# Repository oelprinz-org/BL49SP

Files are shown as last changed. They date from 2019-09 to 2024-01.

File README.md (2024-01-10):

# BL49SP  -  V0.0.3
Wideband Lambda Controller with Bosch CJ125 and LSU 4.9<br/>
Usable as a stand-alone controller or as a add-in for your own design. 2-layer pcb - single side soldered<br/>

20.04.2020 - Version 0.0.1: basic tests are done, seems to be in a working state<br/>

Version 0.0.1 - basic functions implemented: 0,5V - 4,5V equals AFR10-20<br/>

Version 0.0.2 - modifications for automated production process done - PCBs arrived - further tests needed<br/>

Version 0.0.2a - minor corrections on bottom silkscreen<br/>

Version 0.0.3 - minor corrections / pins added to connect OLED-Display<br/>

Update 04.09.2020 - Version 0.0.2: First tests have shown the finished lambda controller in an working state.<br/>
In idle mode Uout is 2,39V (Lambda 1,00).<br/>
In running mode we have a Uout of 4,56V at AFR20 and a Uout of 0,54V at AFR10.<br/>
All measurements have been done with a uncalibrated Multimeter and must be verified with a calibrated device.<br/>
Possibly there is some room for more finetuning or improvements, but until here all looks fine so far. <br/>
Current draw is only some milliAmps in idle mode, something around 1,7 A while heating and 0,7 A in running mode.<br/>

Update 17.09.2020 - Added some illustrations to the wiki how to connect the V0.0.2 board: https://github.com/oelprinz-org/BL49SP/wiki/Connecting-the-board-V0.0.2

V0.0.3 fabrication files for Jlcpcb: https://github.com/oelprinz-org/BL49SP/tree/master/fabrication/V0.0.3

not yet - Precompiled firmware files and fuse settings you can find at https://github.com/oelprinz-org/BL49SP/tree/master/software/V0.0.3/Arduino/BL49SP/Build<br/>

Interactive BOM for easier hand-soldering you can download from the github (BL49SP/hardware/V0.0.3/bom)
or access online here: http://oelprinz.org/products/BL49SP/hardware/V0.0.3/iBOM/ibom.html <br/>

Quick link to schematic: https://github.com/oelprinz-org/BL49SP/blob/master/hardware/V0.0.3/schematics.pdf <br/>

### Bosch CJ125 (LQFP32 package) part numbers

|Bosch part number|
|:----------------|
|30615|
|40103|
|30522|

### Suitable Bosch lambda probes

Basically, the Bosch probes whose numbers start with **0 258 017** will fit, also Bosch **0 281 004**.  
Bosch numbers beginning with **0 258 007** are *LSU 4.2* probes and will not fit.

|Bosch number  |Length overall|Comment|
|---|---|---|
|0 258 017 012 |1060mm||
|0 258 017 025 |1000mm|Bosch motorsport part|
|0 281 004 028 |540mm|common probe for diesel engines|
|0 258 017 029 |620mm|grey, used by BMW after 09/2006 (1178 7539124)|
|0 258 017 038 |340mm|grey, used by BMW (11787537984)|
|0 258 017 092 |950mm|black, used by BMW (1178 7540167)|
|0 258 017 126 |680mm|black, used by BMW after 09/2006 (1178 7561410)|
|0 281 004 150 |1215mm||
|0 281 004 184 |1000mm||
|...|||

### LSU4.9 probe pinout

|Pin#|Color|Description|Symbol|
|----|-----|---|---|
|1|red|Pump current APE|IP|
|2|yellow|Virtual ground IPN|VM|
|3|white|Heater voltage H-|Uh-|
|4|grey|Heater voltaget H+|Uh+|
|5|green|Trim Resistor RT|IA|
|6|black|Nernst voltage UN|RE| <br/>

<p align="center">
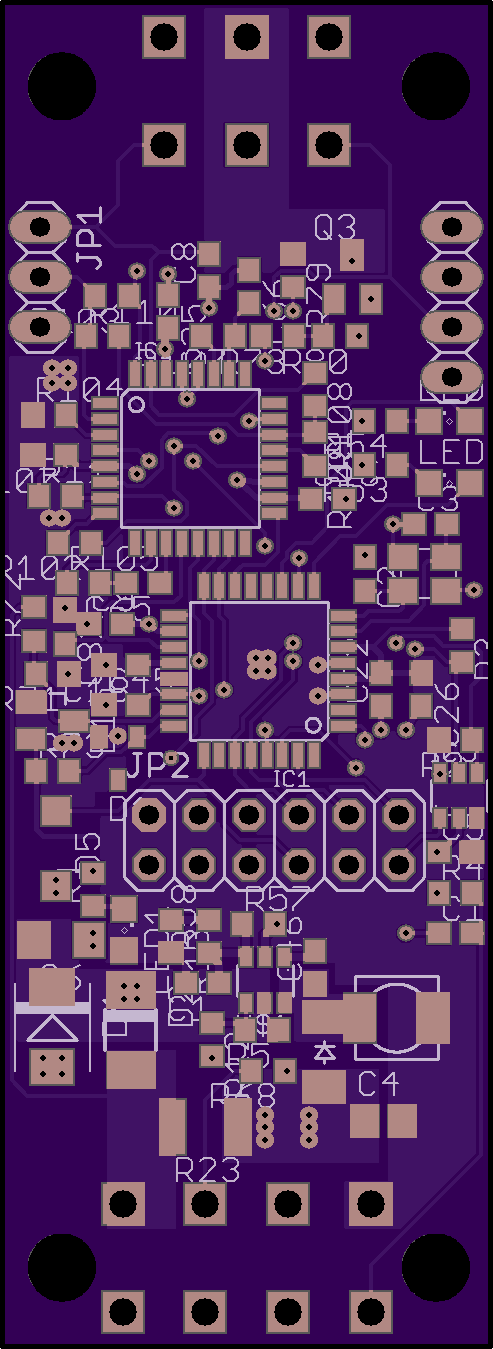
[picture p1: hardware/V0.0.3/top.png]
Top Side
  
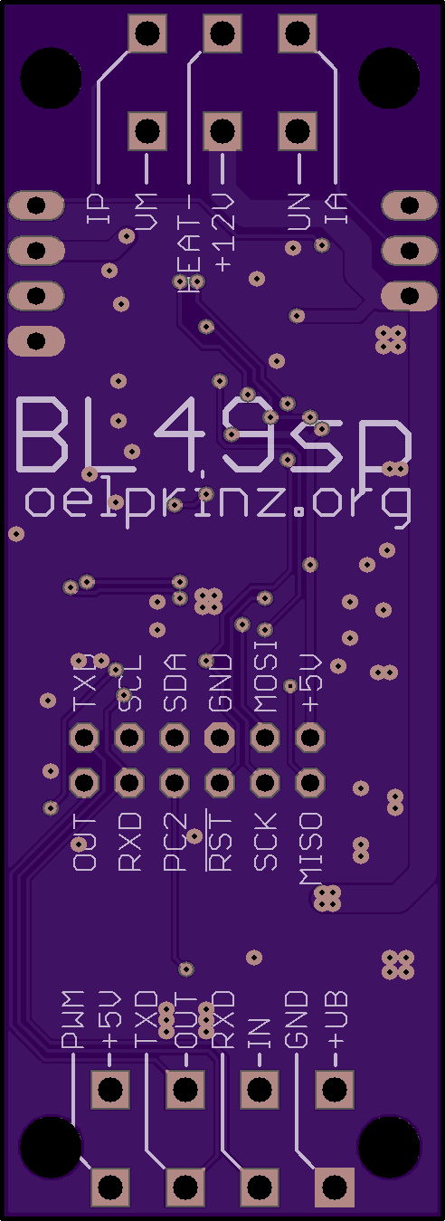
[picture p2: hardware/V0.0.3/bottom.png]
Bottom Side
  <br/>
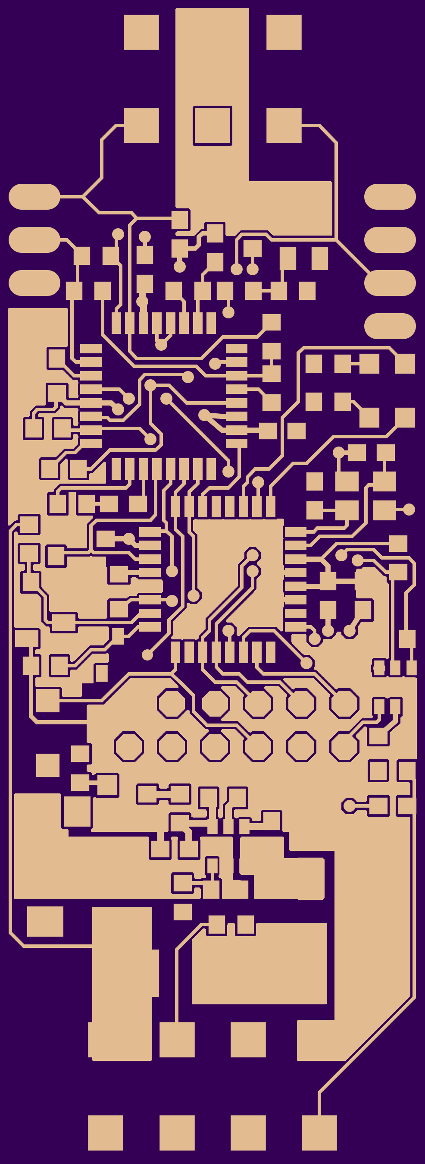
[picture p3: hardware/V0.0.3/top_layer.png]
Top Layer
  
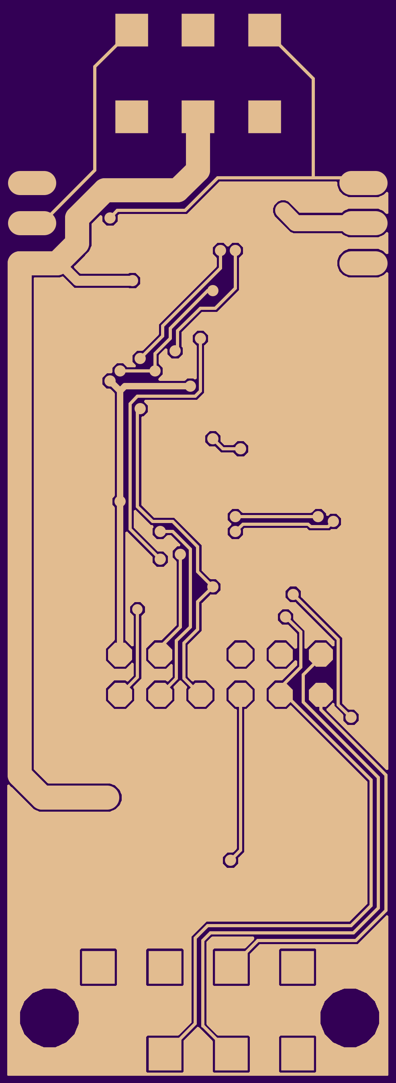
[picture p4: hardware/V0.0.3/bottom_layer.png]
Bottom Layer
  
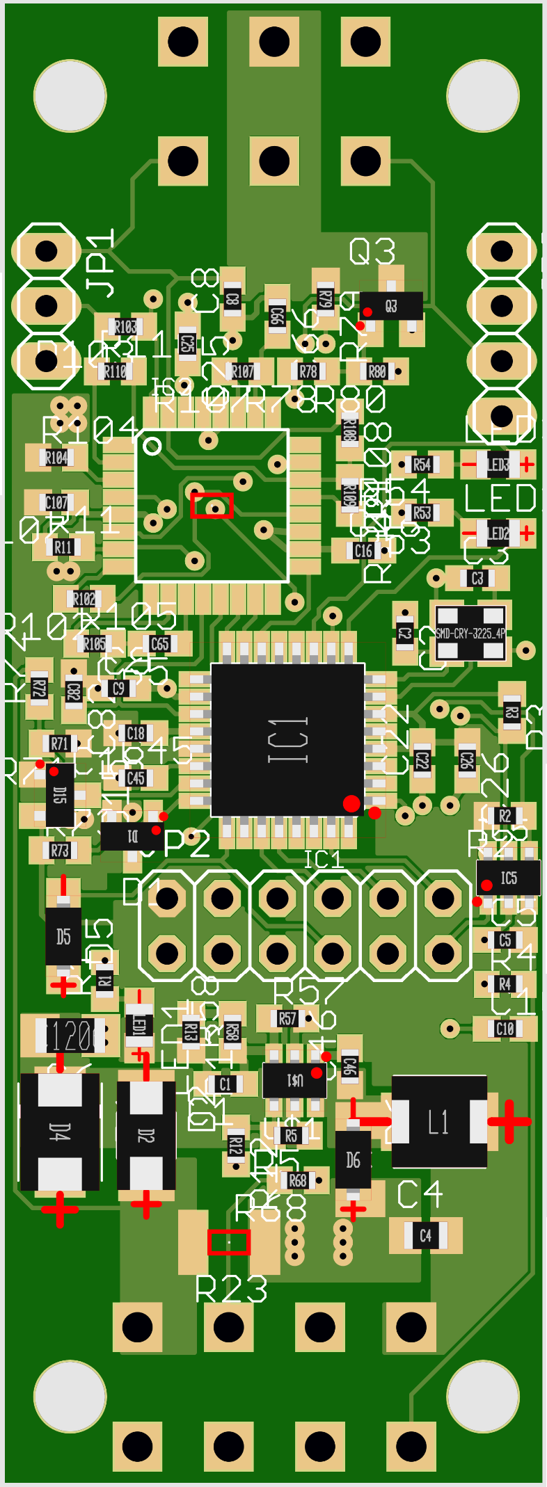
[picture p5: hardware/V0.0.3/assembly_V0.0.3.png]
Assembly
  
  
</p>

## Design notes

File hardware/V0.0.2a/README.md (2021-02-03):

# BL49SP - V0.0.2a

Version 0.0.1 - basic functions implemented: 0,5V - 4,5V equals AFR10-20<br/>

Version 0.0.2 - modifications for automated production process done - PCBs arrived - further tests needed<br/>

Version 0.0.2a - minor corrections on bottom silkscreen<br/>

Update 04.09.2020 - Version 0.0.2: First tests have shown the finished lambda controller in an working state.<br/>
In idle mode Uout is 2,39V (Lambda 1,00).<br/>
In running mode we have a Uout of 4,56V at AFR20 and a Uout of 0,54V at AFR10.<br/>
All measurements have been done with a uncalibrated Multimeter and must be verified with a calibrated device.<br/>
Possibly there is some room for more finetuning or improvements, but until here all looks fine so far. <br/>
Current draw is only some milliAmps in idle mode, something around 1,7 A while heating and 0,7 A in running mode.<br/>

Update 17.09.2020 - Added some illustrations to the wiki how to connect the board: https://github.com/oelprinz-org/BL49SP/wiki/Connecting-the-board-V0.0.2

Update 12.11.2020 - Added fabrication files for Jlcpcb: https://github.com/oelprinz-org/BL49SP/tree/master/fabrication/V0.0.2a

Precompiled firmware files and fuse settings you can find at https://github.com/oelprinz-org/BL49SP/tree/master/software/V0.0.2/Arduino/BL49SP/Build<br/>

Interactive BOM for easier hand-soldering you can download from the github (BL49SP/hardware/V0.0.2/bom)
or access online here: https://oelprinz.000webhostapp.com/BL49SP/V0.0.2/iBOM/ibom.html <br/>

Quick link to schematic: https://github.com/oelprinz-org/BL49SP/blob/master/hardware/V0.0.2/schematics.pdf <br/>

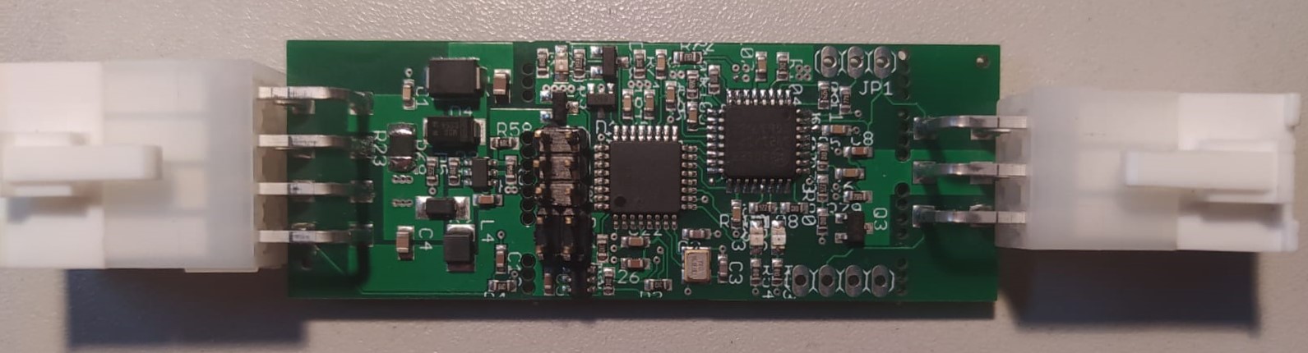
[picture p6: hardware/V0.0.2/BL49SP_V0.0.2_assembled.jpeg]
Assembled Prototype


<p align="center">
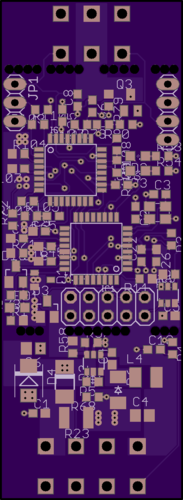
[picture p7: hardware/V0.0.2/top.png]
  
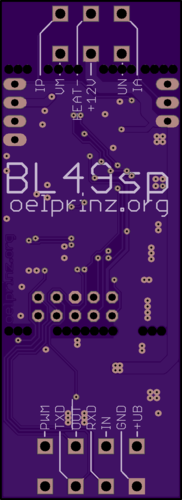
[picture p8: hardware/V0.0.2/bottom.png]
  <br/>
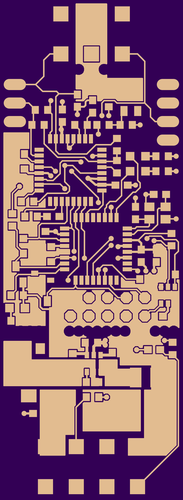
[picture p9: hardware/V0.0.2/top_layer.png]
  
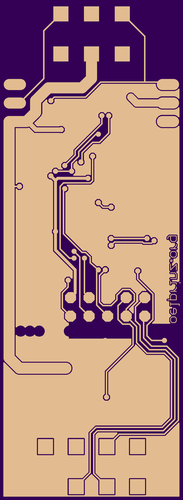
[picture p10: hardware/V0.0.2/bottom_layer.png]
  
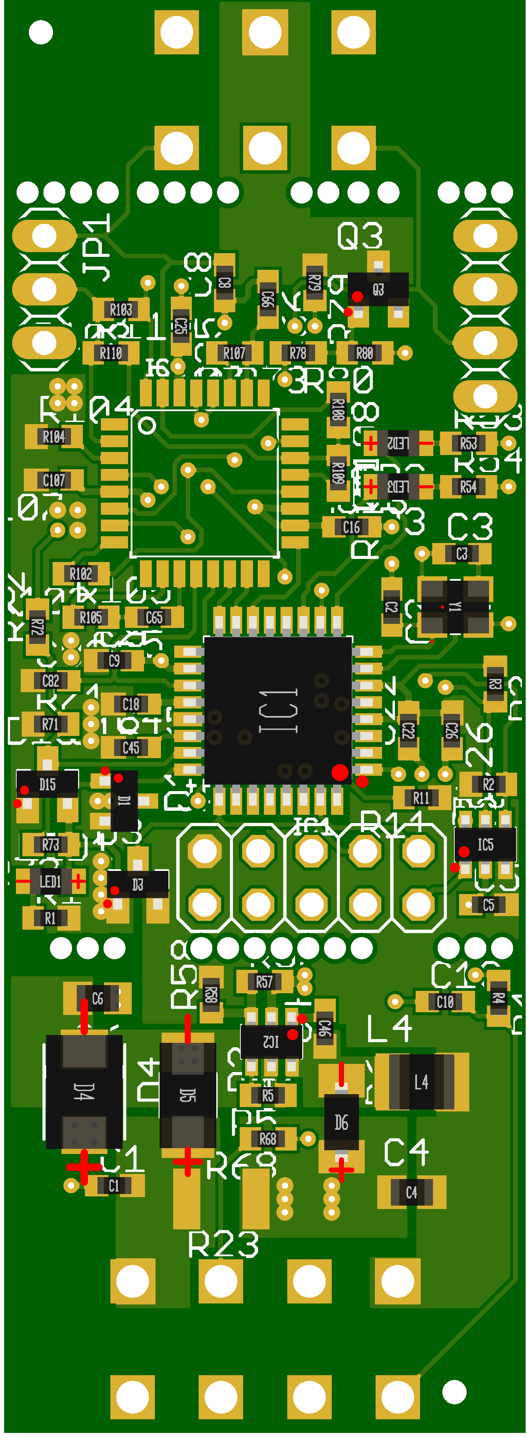
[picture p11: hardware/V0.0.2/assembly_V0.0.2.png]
assembly
  
  
</p>

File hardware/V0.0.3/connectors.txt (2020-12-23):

Needed Connectors and Pins are Molex Mini-Fit Jr 5569:

1x Pin Header 2x4P: 3930-1080
1x Pin Header 2x3P: 3930-1060
1x Contact housing female 2x4P: 3901-2085
1x Contact housing female 2x3P: 3901-2065
14x Crimp socket Female: 3900-0039

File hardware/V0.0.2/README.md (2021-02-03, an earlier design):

# BL49SP - V0.0.2

Version 0.0.1 - basic functions implemented: 0,5V - 4,5V equals AFR10-20<br/>

Version 0.0.2 - modifications for automated production process done - PCBs arrived - further tests needed<br/>

Version 0.0.2a - minor corrections on bottom silkscreen<br/>

Update 04.09.2020 - Version 0.0.2: First tests have shown the finished lambda controller in an working state.<br/>
In idle mode Uout is 2,39V (Lambda 1,00).<br/>
In running mode we have a Uout of 4,56V at AFR20 and a Uout of 0,54V at AFR10.<br/>
All measurements have been done with a uncalibrated Multimeter and must be verified with a calibrated device.<br/>
Possibly there is some room for more finetuning or improvements, but until here all looks fine so far. <br/>
Current draw is only some milliAmps in idle mode, something around 1,7 A while heating and 0,7 A in running mode.<br/>

Update 17.09.2020 - Added some illustrations to the wiki how to connect the board: https://github.com/oelprinz-org/BL49SP/wiki/Connecting-the-board-V0.0.2

Update 12.11.2020 - Added fabrication files for Jlcpcb: https://github.com/oelprinz-org/BL49SP/tree/master/fabrication/V0.0.2a

Precompiled firmware files and fuse settings you can find at https://github.com/oelprinz-org/BL49SP/tree/master/software/V0.0.2/Arduino/BL49SP/Build<br/>

Interactive BOM for easier hand-soldering you can download from the github (BL49SP/hardware/V0.0.2/bom)
or access online here: https://oelprinz.000webhostapp.com/BL49SP/V0.0.2/iBOM/ibom.html <br/>

Quick link to schematic: https://github.com/oelprinz-org/BL49SP/blob/master/hardware/V0.0.2/schematics.pdf <br/>

Assembled Prototype

<p align="center">
  Top Side
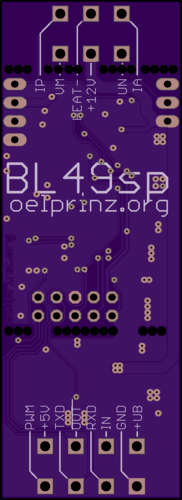
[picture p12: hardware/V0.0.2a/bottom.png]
  <br/>
  Top Side
  accessibility text
  assembly
  
</p>

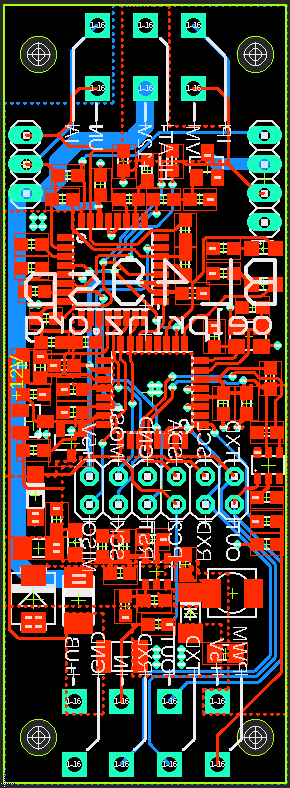
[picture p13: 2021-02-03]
hardware/V0.0.3/BL49SP_Board_V0.0.3.png

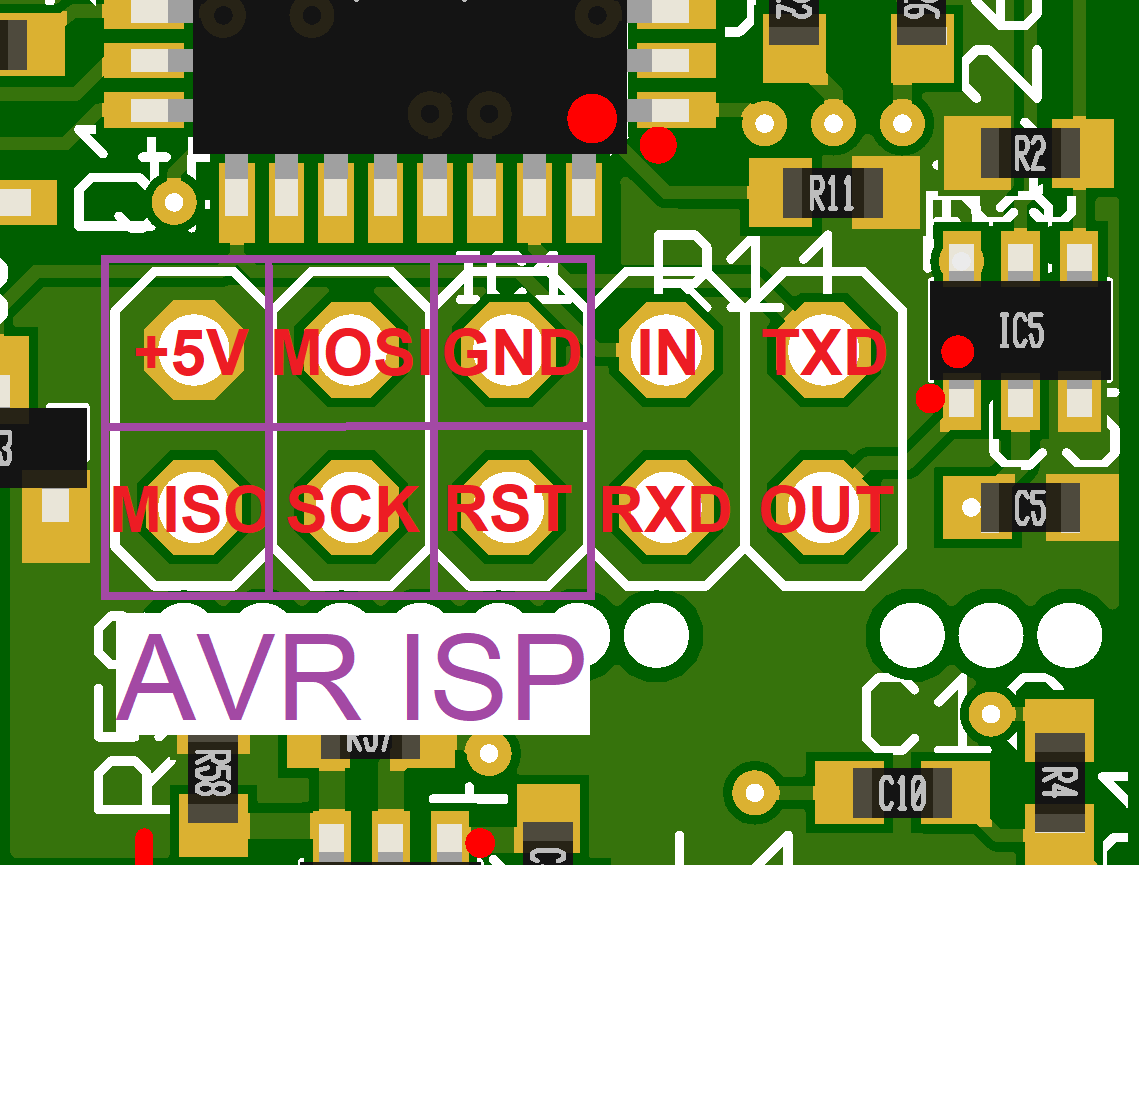
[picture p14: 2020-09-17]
wiki/images/PinHeader.png

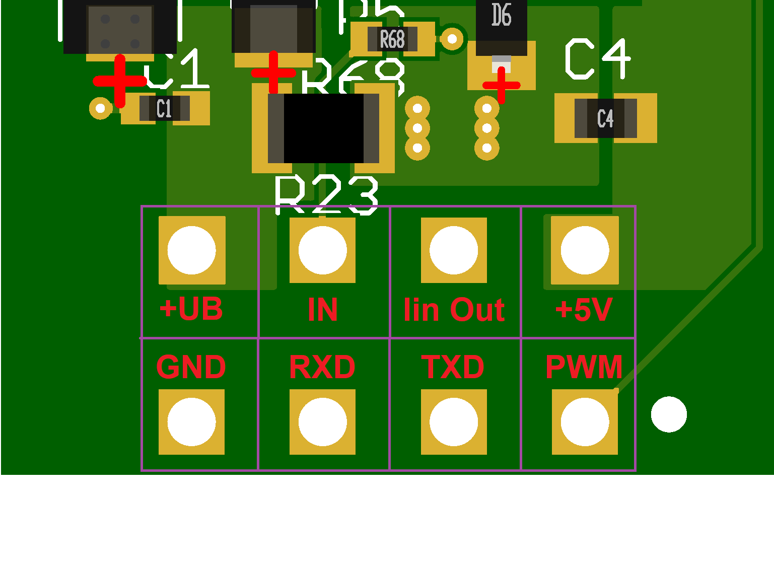
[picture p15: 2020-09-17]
wiki/images/PowerSupply_IOs.png

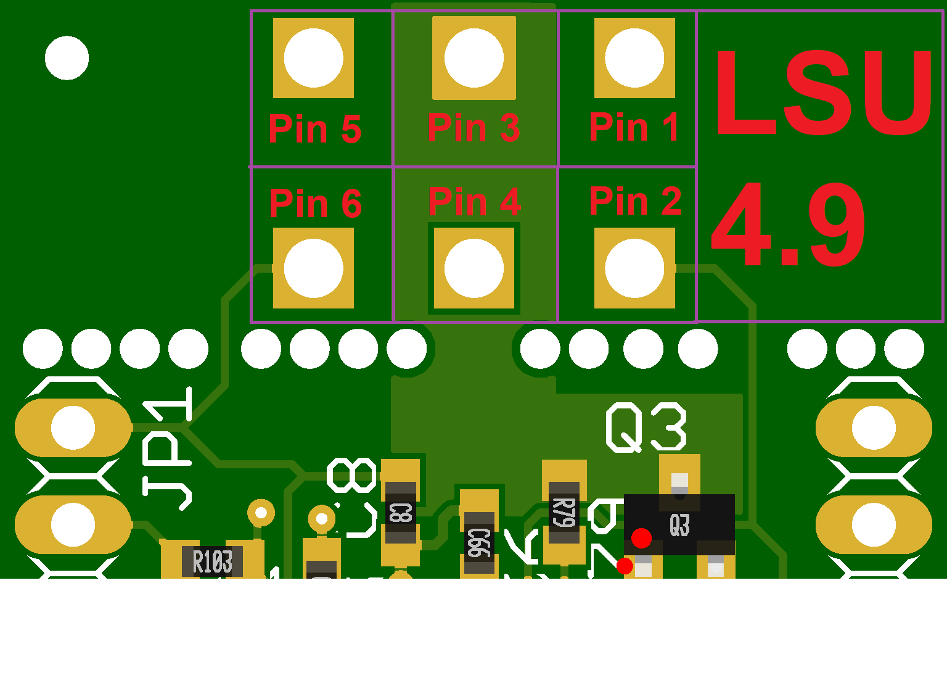
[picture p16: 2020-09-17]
wiki/images/LambdaConnector.png

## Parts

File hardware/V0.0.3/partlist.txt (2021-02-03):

Part     Value           Device          Package          Library                 Sheet

C1       33p             C-EUC0603       C0603            rcl                     1
C2       18p             C-EUC0603       C0603            rcl                     1
C3       18p             C-EUC0603       C0603            rcl                     1
C4       10u             C-EUC0805       C0805            rcl                     1
C5       1u              C-EUC0603       C0603            rcl                     1
C6       22u             C-EUC1206       C1206            rcl                     1
C8       2n2             C-EUC0603       C0603            rcl                     1
C9       100n            C-EUC0603       C0603            rcl                     1
C10      1u              C-EUC0603       C0603            rcl                     1
C16      100n            C-EUC0603       C0603            rcl                     1
C18      100n            C-EUC0603       C0603            rcl                     1
C22      100n            C-EUC0603       C0603            rcl                     1
C25      100n            C-EUC0603       C0603            rcl                     1
C26      1u              C-EUC0603       C0603            rcl                     1
C45      33n             C-EUC0603       C0603            rcl                     1
C46      100n            C-EUC0603       C0603            rcl                     1
C65      100n            C-EUC0603       C0603            rcl                     1
C66      100n            C-EUC0603       C0603            rcl                     1
C82      33n             C-EUC0603       C0603            rcl                     1
C107     100n            C-EUC0603       C0603            rcl                     1
D1       LM4041DIM3-1.2  LM4041A12DBZ    DBZ_R-PDSO-G3    texas                   1
D2       SS54            DIODE-DO-214AC  DO-214AC         diode                   1
D4       SMBJ18A         SUPPRESSOR-SMBJ SMBJ             diode                   1
D5                       DIODE-SOD123    SOD123           diode                   1
D6       B5819W          CGRM4001-G      SOD-123_MINI-SMA diode                   1
D15      BAT54S          BAT54S          SOT23            diode                   1
IC1      MEGA328         MEGA8-AI        TQFP32-08        atmel                   1
IC3      CJ125_32        CJ125_32        TQFP32-08        cj125                   1
IC5      MCP4725         MCP4725         SOT23-6          mcp4725                 1
JP1                      PINHD-1X3       1X03             pinhead                 1
JP2                      PINHD-2X6       2X06             pinhead                 1
JP3                      PINHD-1X4       1X04             pinhead                 1
L1       MWSA0402S-3R3MT MWSA0402S-3R3MT MWSA0402S-3R3MT  MWSA0402S-3R3MT         1
LED1     blau            LEDSML0805      SML0805          led                     1
LED2     blau            LEDSML0805      SML0805          led                     1
LED3     blau            LEDSML0805      SML0805          led                     1
Q3       AO3400A         BSS123          SOT23            transistor-small-signal 1
R1       820R            R-EU_R0603      R0603            rcl                     1
R2       10k             R-EU_R0603      R0603            rcl                     1
R3       10k             R-EU_R0603      R0603            rcl                     1
R4       1k              R-EU_R0603      R0603            rcl                     1
R5       100k            R-EU_R0603      R0603            rcl                     1
R11      10k             R-EU_R0603      R0603            rcl                     1
R12      22k             R-EU_R0603      R0603            rcl                     1
R13      100k            R-EU_R0603      R0603            rcl                     1
R23      B72530V1140S262 VARISTORCN1210  CT/CN1210        varistor                1
R53      1k              R-EU_R0603      R0603            rcl                     1
R54      1k              R-EU_R0603      R0603            rcl                     1
R57      24k             R-EU_R0603      R0603            rcl                     1
R58      24k             R-EU_R0603      R0603            rcl                     1
R68      470R            R-EU_R0603      R0603            rcl                     1
R71      10k             R-EU_R0603      R0603            rcl                     1
R72      39k             R-EU_R0603      R0603            rcl                     1
R73      39k             R-EU_R0603      R0603            rcl                     1
R78      4k7             R-EU_R0603      R0603            rcl                     1
R79      6k8             R-EU_R0603      R0603            rcl                     1
R80      100k            R-EU_R0603      R0603            rcl                     1
R102     300/1%          R-EU_R0603      R0603            rcl                     1
R103     61R9            R-EU_R0603      R0603            rcl                     1
R104     10k             R-EU_R0603      R0603            rcl                     1
R105     31k6/1%         R-EU_R0603      R0603            rcl                     1
R107     100k            R-EU_R0603      R0603            rcl                     1
R108     100k            R-EU_R0603      R0603            rcl                     1
R109     4k7             R-EU_R0603      R0603            rcl                     1
R110     470k            R-EU_R0603      R0603            rcl                     1
U$1      MP2451          MP2359          SOT23-6          MP2359                  1
U$4      X322516MLB4SI   X322516MLB4SI   X322516MLB4SI    X322516MLB4SI           1

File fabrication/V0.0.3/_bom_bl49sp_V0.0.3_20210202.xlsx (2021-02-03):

Comment | Value | Designator | Footprint | LCSC Part #
0603WAF1003T5E | 100kΩ ±1% 0.1W ±100ppm/℃ 0603 Chip Resistor - Surface Mount | R5,R13,R80,R107,R108 | 0603_R | C25803 (https://lcsc.com/product-detail/Chip-Resistor-Surface-Mount_Uniroyal-Elec-0603WAF1003T5E_C25803.html/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)
CC0603KRX7R9BB104 | 100nF ±10% 50V X7R 0603 Multilayer Ceramic Capacitors MLCC – SMD/SMT | C9,C16,C18,C22,C25,C46,C65,C66,C107 | 0603_C | C14663 (https://lcsc.com/product-detail/Multilayer-Ceramic-Capacitors-MLCC-SMD-SMT_100nF-104-10-50V_C14663.html/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)
0603WAF1002T5E | 10kΩ ±1% 0.1W ±100ppm/℃ 0603 Chip Resistor - Surface Mount | R2,R3,R11,R71,R104 | 0603_R | C25804 (https://lcsc.com/product-detail/Chip-Resistor-Surface-Mount_Uniroyal-Elec-0603WAF1002T5E_C25804.html/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)
MM1Z5V1 | ZENER DIODE 5,1V | D5 | SOD-123 | C81601 (https://lcsc.com/product-detail/Zener-Diodes_MM1Z5V1_C81601.html/?href=jlc-SMT)
CL10C180JB8NNNC | 18pF ±5% 50V C0G 0603 Multilayer Ceramic Capacitors MLCC – SMD/SMT | C2,C3 | 0603_C | C1647 (https://lcsc.com/product-detail/Multilayer-Ceramic-Capacitors-MLCC-SMD-SMT_SAMSUNG_CL10C180JB8NNNC_18pF-180-5-50V_C1647.html/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)
0603WAF8200T5E | 820Ω ±1% 0.1W ±100ppm/℃ 0603 Chip Resistor - Surface Mount | R1 | 0603_R | C23253 (https://lcsc.com/product-detail/Chip-Resistor-Surface-Mount_Uniroyal-Elec-0603WAF8200T5E_C23253.html/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)
0603WAF1001T5E | 1kΩ ±1% 0.1W ±100ppm/℃ 0603 Chip Resistor - Surface Mount | R4,R53,R54 | 0603_R | C21190 (https://lcsc.com/product-detail/Chip-Resistor-Surface-Mount_Uniroyal-Elec-0603WAF1001T5E_C21190.html/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)
CL10C330JB8NNNC | 33pF ±10% 50V X7R 0603 Multilayer Ceramic Capacitors MLCC – SMD/SMT | C1 | 0603_C | C1663 (https://lcsc.com/product-detail/Multilayer-Ceramic-Capacitors-MLCC-SMD-SMT_SAMSUNG_CL10C330JB8NNNC_33pF-330-5-50V_C1663.html/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)
CL10A105KB8NNNC | 1uF ±10% 50V X5R 0603 Multilayer Ceramic Capacitors MLCC – SMD/SMT | C5,C10,C26 | 0603_C | C15849 (https://lcsc.com/product-detail/Multilayer-Ceramic-Capacitors-MLCC-SMD-SMT_SAMSUNG_CL10A105KB8NNNC_1uF-105-10-50V_C15849.html/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)
CL21A106KAYNNNE | 10uF ±20% 25V X5R 0805 Multilayer Ceramic Capacitors MLCC – SMD/SMT | C4 | 0805_C | C15850 (https://lcsc.com/product-detail/Multilayer-Ceramic-Capacitors-MLCC-SMD-SMT_SAMSUNG_CL21A106KAYNNNE_10uF-106-10-25V_C15850.html/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)
C3216X5R1V226MTJ00E | 22UF ±20% 35V X5R 1206 MULTILAYER CERAMIC CAPACITORS MLCC | C6 | 1206_C | C342620 (https://lcsc.com/product-detail/Multilayer-Ceramic-Capacitors-MLCC-SMD-SMT_TDK-C3216X5R1V226MTJ00E_C342620.html/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)
0603B222K500NT | 2.2nF ±10% 50V X7R 0603 Multilayer Ceramic Capacitors MLCC - SMD/SMT | C8 | 0603_C | C1604 (https://lcsc.com/product-detail/Multilayer-Ceramic-Capacitors-MLCC-SMD-SMT_2-2nF-222-10-50V_C1604.html/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)
0603WAF3000T5E | 300Ω ±1% 0.1W ±100ppm/℃ 0603 Chip Resistor - Surface Mount | R102 | 0603_R | C23025
0603WAF3162T5E | 31.6kΩ ±1% ±1% 0.1W ±100ppm/℃ 0603 Chip Resistor - Surface Mount | R105 | 0603_R | C25967 (https://lcsc.com/product-detail/Chip-Resistor-Surface-Mount_Uniroyal-Elec-0603WAF3162T5E_C25967.html/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)
CL10B333KB8NNNC | 33nF ±10% 50V X7R 0603 Multilayer Ceramic Capacitors MLCC – SMD/SMT | C45,C82 | 0603_C | C21117 (https://lcsc.com/product-detail/Multilayer-Ceramic-Capacitors-MLCC-SMD-SMT_SAMSUNG_CL10B333KB8NNNC_33nF-333-10-50V_C21117.html/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)
0603WAF3902T5E | 39kΩ ±1% 0.1W ±100ppm/℃ 0603 Chip Resistor - Surface Mount | R72,R73 | 0603_R | C23153 (https://lcsc.com/product-detail/Chip-Resistor-Surface-Mount_Uniroyal-Elec-0603WAF3902T5E_C23153.html/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)
0603WAF2402T5E | 24kΩ ±1% 0.1W ±100ppm/℃ 0603 Chip Resistor - Surface Mount | R57,R58 | 0603_R | C23352 (https://lcsc.com/product-detail/Chip-Resistor-Surface-Mount_Uniroyal-Elec-0603WAF2402T5E_C23352.html/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)
0603WAF4703T5E | 470kΩ ±1% 0.1W ±100ppm/℃ 0603 Chip Resistor - Surface Mount | R110 | 0603_R | C23178 (https://lcsc.com/product-detail/Chip-Resistor-Surface-Mount_Uniroyal-Elec-0603WAF4703T5E_C23178.html/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)
0603WAF4700T5E | 470Ω ±1% 0.1W ±100ppm/℃ 0603 Chip Resistor - Surface Mount | R68 | 0603_R | C23179 (https://lcsc.com/product-detail/Chip-Resistor-Surface-Mount_Uniroyal-Elec-0603WAF4700T5E_C23179.html/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)
0603WAF4701T5E | 4.7kΩ ±1% 0.1W ±100ppm/℃ 0603 Chip Resistor - Surface Mount | R78,R109 | 0603_R | C23162 (https://lcsc.com/product-detail/Chip-Resistor-Surface-Mount_Uniroyal-Elec-0603WAF4701T5E_C23162.html/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)
0603WAF619JT5E | 61.9Ω ±1% 0.1W ±200ppm/℃ 0603 Chip Resistor - Surface Mount | R103 | 0603_R | C23092 (https://lcsc.com/product-detail/Chip-Resistor-Surface-Mount_Uniroyal-Elec-0603WAF619JT5E_C23092.html/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)
0603WAF2202T5E | 22kΩ ±1% 0.1W ±100ppm/℃ 0603 Chip Resistor - Surface Mount | R12 | 0603_R | C31850 (https://lcsc.com/product-detail/Chip-Resistor-Surface-Mount_Uniroyal-Elec-0603WAF2202T5E_C31850.html/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)
0603WAF6801T5E | 6.8kΩ ±1% 0.1W ±100ppm/℃ 0603 Chip Resistor - Surface Mount | R79 | 0603_R | C23212 (https://lcsc.com/product-detail/Chip-Resistor-Surface-Mount_Uniroyal-Elec-0603WAF6801T5E_C23212.html/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)
B5819W | 40V 1A 600mV @ 1A SOD-123 Schottky Barrier Diodes (SBD) | D6 | SOD-123 | C8598
B72530V1140S262 | 22V 400A Varistor Circuit Surface Mount, MLCV 1210 (3225 Metric) | R23 | CT/CN1210 | n/a
BAT54S | 30V 200mA 800mV @ 100mA SOT-23(SOT-23-3) Schottky Barrier Diodes (SBD) | D15 | SOT23 | C181201 (https://lcsc.com/product-detail/Schottky-Barrier-Diodes-SBD_BAT54S_C181201.html/?href=jlc-SMT)
CJ125_32 | Bosch CJ125 (30522) | IC3 | TQFP32-08 | n/a
AO3400A | N Channel 30V 5.7A 1.5V @ 250uA 26.5mΩ @ 5.7A,10V 1.4W SOT-23-3L MOSFET | Q3 | SOT-23-3L | C347475
LM4041C12IDBZR | Voltage References 1.225V ±0.5% 100ppm/°C SOT-23 | D1 | SOT-23-3 | C189195
MWSA0402S-3R3MT | 3.3UH ±20% 3.3A 87MΩ SMD,4.2X4.4X2.0MM POWER INDUCTORS | L1 | SMD-4.2x4.4x2.0 | C408336 (https://lcsc.com/product-detail/Power-Inductors_Sunlord-MWSA0402S-3R3MT_C408336.html/?href=jlc-SMT)
MCP4725A0T-E/CH | Voltage-Buffered I2C SOT-23-6 Digital To Analog Converters (DACs) | IC5 | SOT23-6 | C144198 (https://lcsc.com/product-detail/Digital-To-Analog-Converters-DACs_MICROCHIP_MCP4725A0T-E-CH_MCP4725A0T-E-CH_C144198.html/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)
ATMEGA328P-AU | 8-Bit FLASH AVR 20MHz 1.8V ~ 5.5V TQFP-32_7x7x08P ATMEL & AVR | IC1 | TQFP32-08 | C14877 (https://lcsc.com/product-detail/ATMEL-AVR_ATMEL_ATMEGA328P-AU_ATMEGA328P-AU_C14877.html/?href=jlc-SMT)
MP2451DT-LF-Z | TSOT-23-6 DC-DC Converters | U$1 | TSOT-23-6 | C14123 (https://lcsc.com/product-detail/DC-DC-Converters_MPS_MP2451DT-LF-Z_MP2451DT-LF-Z_C14123.html/?href=jlc-SMT)
SMBJ18A | TVS SMB(DO-214AA) ROHS | D4 | DO-214AA | C78412
SS54 | 40V 5A 550mV @ 5A SMA(DO-214AC) Schottky Barrier Diodes (SBD) | D2 | DO-214AA | C22452 (https://lcsc.com/product-detail/Schottky-Barrier-Diodes-SBD_MDD-Microdiode-Electronics-SS54_C22452.html/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)
LEDBLUE0805 | 0805 Light Emitting Diodes (LED) blue | LED1 | SML0805 | C2293 (https://lcsc.com/product-detail/Light-Emitting-Diodes-LED_Hubei-KENTO-Elec-Blue-light_C2293.html/?href=jlc-SMT)
FC-2012HRK-620D | 0805 Light Emitting Diodes (LED) red | LED2 | SML0805 | C84256 (https://lcsc.com/product-detail/Light-Emitting-Diodes-LED_Red-LED-SMDLED-80-180mcd_C84256.html/?href=jlc-SMT)
LEDGREEN0805 | 0805 Light Emitting Diodes (LED) green | LED3 | SML0805 | C2297 (https://lcsc.com/product-detail/Light-Emitting-Diodes-LED_Green-0805-Iv-207-249-mcd-atIF-20mA_C2297.html/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)
X322516MLB4SI | SMD CRYSTAL RESONATORS 16MHZ ±10PPM SMD-3225_4P | U$4 | SMD-3225 | C13738 (https://lcsc.com/product-detail/SMD-Crystal-Resonators_Yangxing-Tech-X322516MLB4SI_C13738.html/?href=jlc-SMT)
 | D5

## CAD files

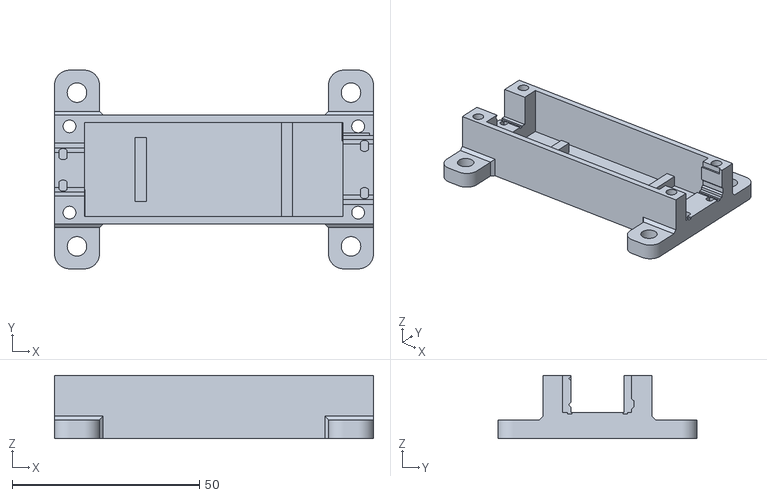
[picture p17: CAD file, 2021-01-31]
hardware/case/Case_V0.0.2a.stl
85.1 x 53.0 x 16.9

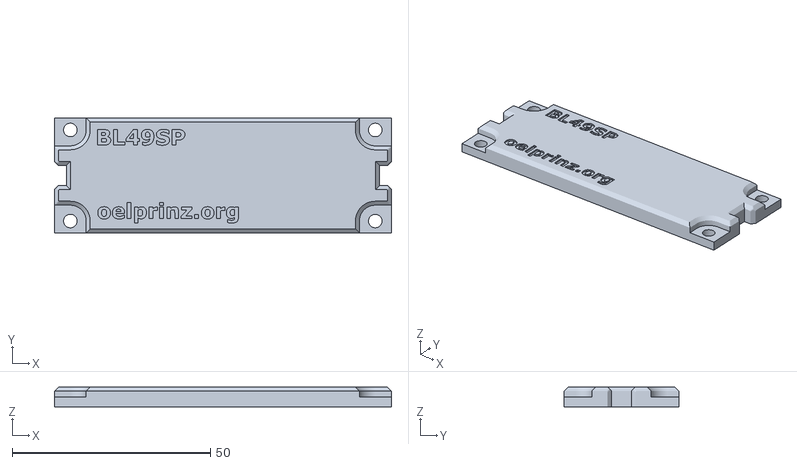
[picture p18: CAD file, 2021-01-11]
hardware/case/Cover_V0.0.2a.stl
85.1 x 29.0 x 5.00

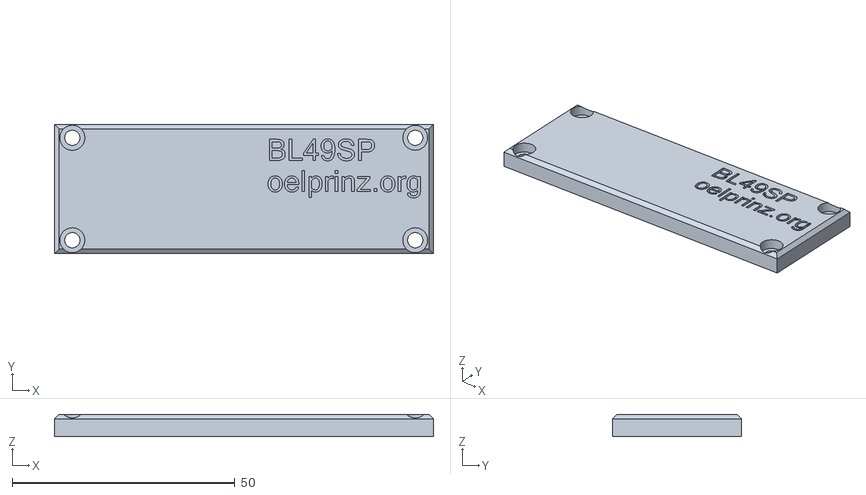
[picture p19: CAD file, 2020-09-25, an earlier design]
hardware/case/archive/Cover_V0.0.2.stl
85.1 x 29.0 x 5.00

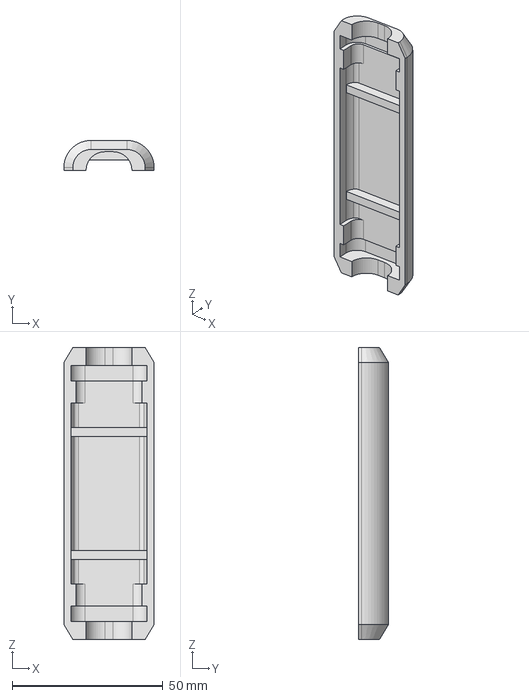
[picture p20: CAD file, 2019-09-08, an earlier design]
hardware/case/archive/case_bl49sp.stp
30.0 x 10.0 x 97.0 mm

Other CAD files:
hardware/case/Cover_V0.0.2a_2LED.stl
hardware/case/Cover_V0.0.2a_1LED.stl
hardware/case/archive/case_bl49sp.stl

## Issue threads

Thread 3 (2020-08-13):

Is there a BOM to enable parts ordering?

84ace, 2020-08-13:
Hi,

I noticed that the BOM and parts list can't really be used to identify the parts needed to assemble the board. Is there a parts reference somewhere so that I can order the parts needed.

Also, is there a KiCad .pro somewhere so that changes can be made?

Cheers,
Acea

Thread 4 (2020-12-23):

Connector types

h2oo2h, 2020-12-23:
What type of connectors do you use for sensor and supply?

chaoschris, 2020-12-23:
Hello,
needed Connectors and Pins are Molex Mini-Fit Jr 5569 :
1x Pin Header 2x4P: 3930-1080
1x Pin Header 2x3P: 3930-1060
1x Contact housing female 2x4P: 3901-2085
1x Contact housing female 2x3P: 3901-2065
14x Crimp socket Female: 3900-0039

Best regards,
Chris

Zitat von h2oo2h <notifications@github.com>:

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

chaoschris, 2020-12-23:
added the information now:
https://github.com/oelprinz-org/BL49SP/blob/master/hardware/V0.0.2/connectors.txt

Closed 2020-12-23.

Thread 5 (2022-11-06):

Stuck on preheat

dener4321, 2022-11-06:
```
	/* one step every second */
	if ((Abl.Tick - Abl.LastHeatTick) >= PROBE_PREHEAT_PERIOD)
	{
		/* Toggle heater LED */
		Out.Led2 ^= 1;
		/* Check if we have reached end phase */
		if ((Out.Heater >= end) || (In.UR < Abl.UROpt))
		{
			Abl.Mode = RUNNING;
		}
		else
		{
			Out.Heater += step;
			/* Limit heater voltage to end pulse width */
			if (Out.Heater > end) Out.Heater = end;
		}
		/* Save tick count */
		Abl.LastHeatTick = Abl.Tick
```

I seem to have encountered a problem in this code.
Out.heater += step
For example if you add 252 + 7 it won't give 259 it will give 3 because the variable is of type uint8 it goes up to 255 only. Then it will restart the heating process.

chaoschris, 2022-11-18:
Have you tested the corrected version of the software?

dener4321, 2023-01-20:
> Have you tested the corrected version of the software?

yes it is working

Closed 2023-01-20.

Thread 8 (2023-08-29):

Can't get it to burn bootloader.

GarrdenDog, 2023-08-29:
Hey, I've tried everything to upload sketch or burn bootloader(uspasp, ttl, arduino as isp) always throws error (not detecting, difrent signature or smth else)
avrdude: Yikes!  Invalid device signature.
         Double check connections and try again, or use -F to override
         this check.
or
stk500_recv()
The atmega was ordered from jlcpcb and soldered by them.
I ve tried uploading on not asembled board and fully aseambled board.

GarrdenDog, 2023-08-29:
avrdude: Version 6.3-20190619
         Copyright (c) 2000-2005 Brian Dean, http://www.bdmicro.com/
         Copyright (c) 2007-2014 Joerg Wunsch

         System wide configuration file is "C:\Users\mmuch\AppData\Local\Arduino15\packages\arduino\tools\avrdude\6.3.0-arduino17/etc/avrdude.conf"

         Using Port                    : COM6
         Using Programmer              : arduino
         Overriding Baud Rate          : 19200
         AVR Part                      : ATmega328P
         Chip Erase delay              : 9000 us
         PAGEL                         : PD7
         BS2                           : PC2
         RESET disposition             : dedicated
         RETRY pulse                   : SCK
         serial program mode           : yes
         parallel program mode         : yes
         Timeout                       : 200
         StabDelay                     : 100
         CmdexeDelay                   : 25
         SyncLoops                     : 32
         ByteDelay                     : 0
         PollIndex                     : 3
         PollValue                     : 0x53
         Memory Detail                 :

                                  Block Poll               Page                       Polled
           Memory Type Mode Delay Size  Indx Paged  Size   Size #Pages MinW  MaxW   ReadBack
           ----------- ---- ----- ----- ---- ------ ------ ---- ------ ----- ----- ---------
           eeprom        65    20     4    0 no       1024    4      0  3600  3600 0xff 0xff
           flash         65     6   128    0 yes     32768  128    256  4500  4500 0xff 0xff
           lfuse          0     0     0    0 no          1    0      0  4500  4500 0x00 0x00
           hfuse          0     0     0    0 no          1    0      0  4500  4500 0x00 0x00
           efuse          0     0     0    0 no          1    0      0  4500  4500 0x00 0x00
           lock           0     0     0    0 no          1    0      0  4500  4500 0x00 0x00
           calibration    0     0     0    0 no          1    0      0     0     0 0x00 0x00
           signature      0     0     0    0 no          3    0      0     0     0 0x00 0x00

         Programmer Type : Arduino
         Description     : Arduino
         Hardware Version: 2
         Firmware Version: 1.18
         Topcard         : Unknown
         Vtarget         : 0.0 V
         Varef           : 0.0 V
         Oscillator      : Off
         SCK period      : 0.1 us

avrdude: AVR device initialized and ready to accept instructions

Błąd przy wgrywaniu bootloadera.
Reading | ################################################## | 100% 0.00s

avrdude: Device signature = 0x535353
avrdude: Expected signature for ATmega328P is 1E 95 0F
         Double check chip, or use -F to override this check.

avrdude done.  Thank you.

chaoschris, 2023-08-31:
have you tested all connections between your programmer and the pins on the Atmega? One-by-one?

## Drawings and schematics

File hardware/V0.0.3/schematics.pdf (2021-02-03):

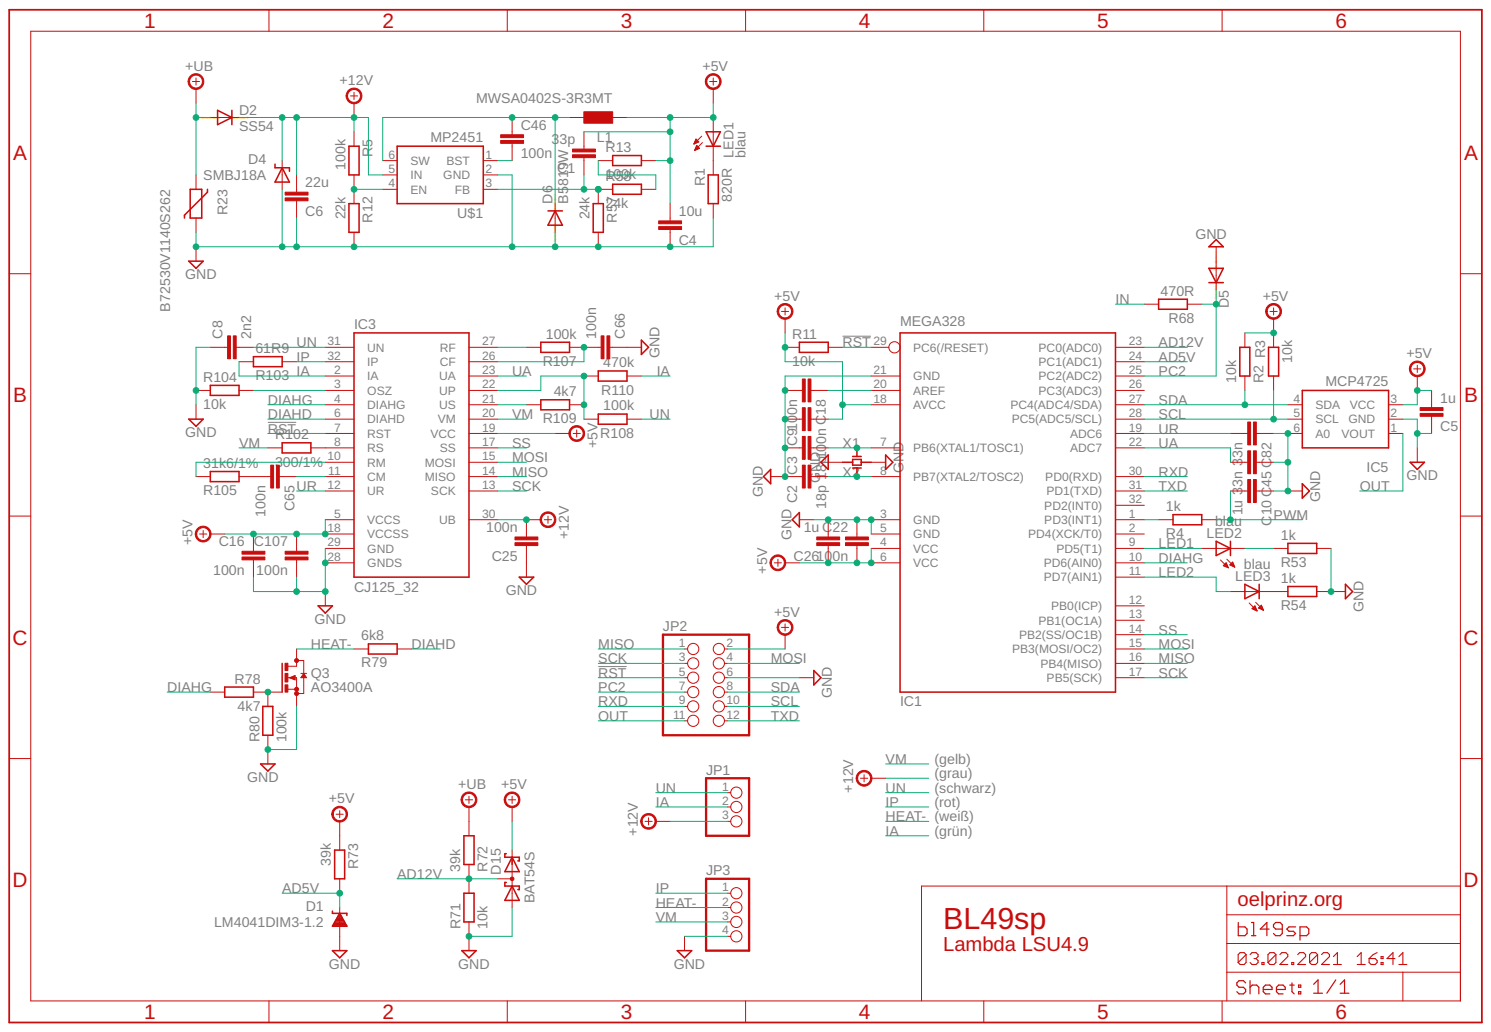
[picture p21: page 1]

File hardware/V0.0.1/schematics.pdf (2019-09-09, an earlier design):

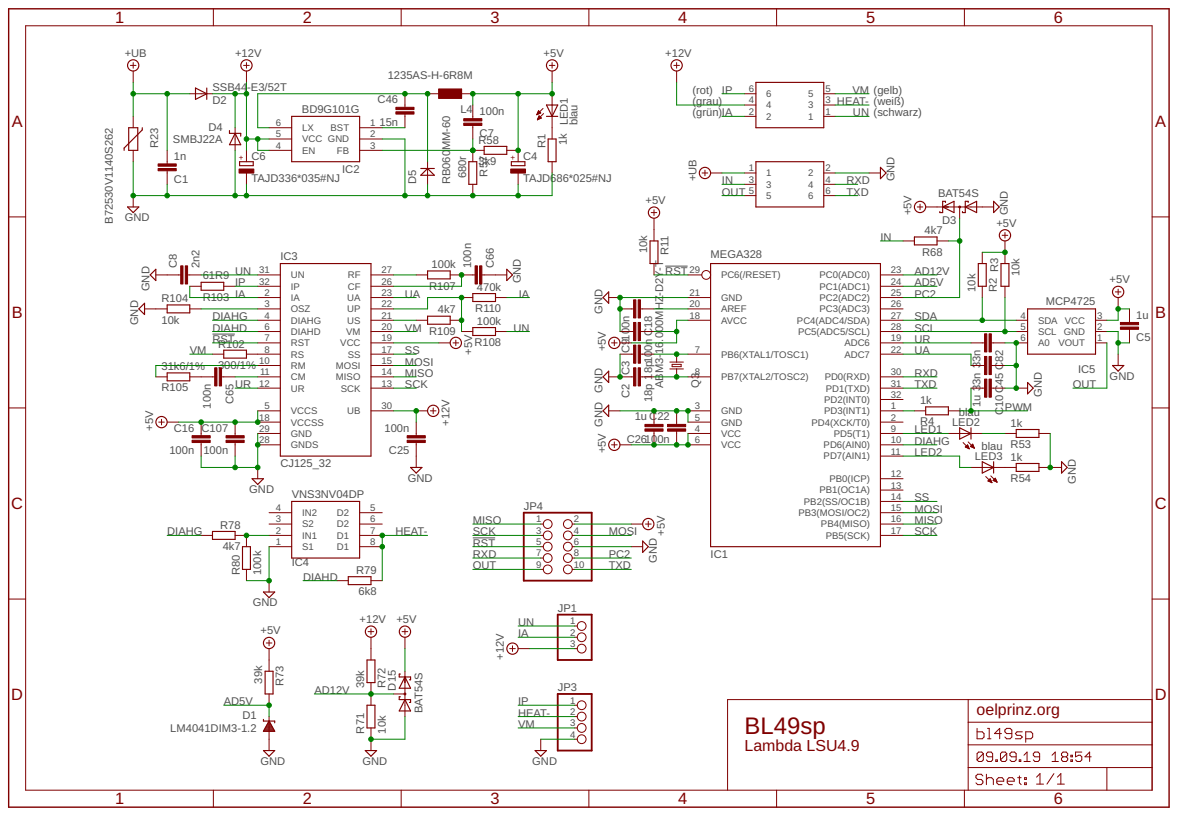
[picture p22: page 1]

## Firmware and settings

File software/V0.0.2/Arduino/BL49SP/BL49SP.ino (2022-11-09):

/* LambdaCtrl.h
 *
 *	This programm is designed to build a standalone wideband lambda controller.
 *	It's based on BOSCH CJ125 which is the interface between the lambda probe and the uC.
 *	
 *	Hardware open source BL49sp
 *	Software (c) Alfagta --> Mario Schoebinger
 *
 *	LambdaCtrl is licensed under a
 *	Creative Commons Attribution-NonCommercial 4.0 International License.
 *
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
 **/

#include "LambdaCtrl.h"

/* Global variables */
tCfg Cfg;
tAbl Abl;
tInputs In;
tOutputs Out;
tCj125 Cj;

/* Objects */
FastPID HeaterPid;

void setup()
{
	/* Reset structs */
	memset((void*)&Abl, 0, sizeof(Abl));
	memset((void*)&In, 0, sizeof(In));
	memset((void*)&Out, 0, sizeof(Out));
	memset((void*)&Cj, 0, sizeof(Cj));
	
	/* Read config from eeprom */
	eeprom_read_block((void*)&Cfg, 0, sizeof(Cfg));
	
	/* Setup io's */
	pinMode(CJ125_NSS_PIN, OUTPUT);
	pinMode(LED_STATUS_POWER, OUTPUT);
	pinMode(LED_STATUS_HEATER, OUTPUT);
	pinMode(HEATER_OUTPUT_PIN, OUTPUT);
	pinMode(LAMBDA_PWM_OUTPUT_PIN, OUTPUT);
	pinMode(EN_INPUT_PIN, INPUT_PULLUP);
//	pinMode(SP1_INPUT_PIN, INPUT_PULLUP);
//	pinMode(SP2_INPUT_PIN, INPUT_PULLUP);
	
	/* Change PWM frequency for heater pin to 122Hz */
	TCCR1B = 1 << CS12;
	/* Set I2C frequency to 400kHz */
	TWBR = ((F_CPU / 400000L) - 16) / 2;
		
	/* Preset io's */
	digitalWrite(CJ125_NSS_PIN, HIGH);
	digitalWrite(LED_STATUS_POWER, LOW);
	digitalWrite(LED_STATUS_HEATER, LOW);
	digitalWrite(HEATER_OUTPUT_PIN, LOW);
	digitalWrite(LAMBDA_PWM_OUTPUT_PIN, LOW);
	
	/* Init objects */
	HeaterPid.configure(17.0, 3.0, 0.7, 100, 8, false);

	SPI.begin();  
	SPI.setClockDivider(SPI_CLOCK_DIV8);
	SPI.setBitOrder(MSBFIRST);
	SPI.setDataMode(SPI_MODE1);
	
	Wire.begin();
	
	/* Serial */
	Serial.begin(115200);
	
	/* Wait a little bit, CJ125 needs some time for start up*/
	delay(250);
}

void loop()
{
	/* Read Inputs */	
	Inputs(&In);
	
	/* Read tick */
	Abl.Tick = millis();
	
	/* Reference voltage */
	Abl.RefVoltage = (int16_t)((uint32_t)In.URef * 5000UL / 1023UL);	//This should be exactly 1.225V so we can calculate the adc offset from this
	/* Calculate the voltage offset */
	Abl.VoltageOffset = 1225 - Abl.RefVoltage;
	/* Calculate battery voltage */
	Abl.SupplyVoltage = Abl.VoltageOffset + (int16_t)((uint32_t)In.USup * 25230UL / 1023UL);
	/* Sanity check for battery voltage */
	if (CheckUBatt() == false)
	{		
		if (Abl.Mode != PRESET) Abl.Mode = PRESET;		
	}	
	
	/* Jump to the current mode function */
	switch (Abl.Mode)
	{
	case INVALID:
		Abl.Mode = PRESET;
		break;
		
	case PRESET:
		Preset();
		break;
		
	case START:
		Start();
		break;
		
	case CALIBRATION:
		Calibrate();
		break;
		
	case IDLE:
		Idle();
		break;
		
	case CONDENSATE:
		Condensate();
		break;
		
	case PREHEAT:
		Preheat();
		break;
		
	case RUNNING:
		Running();
		break;	
	
	case ERROR:
		Error();
		break;
		
	default:
		Abl.Mode = PRESET;
		break;			
	}	
	
	/* Write Outputs */
	Outputs(&Out);

	/* Update Serial port in debug mode */
	if ((Abl.Tick - Abl.LastSerialTick) >= 150)
	{
		if (Abl.Mode == PRESET)
		{
			Out.Led1 ^= 1;
		}
		
#if (DEBUG > 1)
		Serial.print("UR:");
		Serial.println(In.UR);		
		Serial.print("UA:");
		Serial.println(In.UA);
		Serial.print("IP:");
		Serial.println(Cj.IP);	
#endif
#if (DEBUG > 0)
		Serial.print("Mode:");
		Serial.println(ModeName[Abl.Mode]);	
		Serial.print("Supply:");
		Serial.println(Abl.SupplyVoltage / 1000.0);	
		if (Abl.CjState != cjERROR)
		{
			Serial.print("Lambda:");
			Serial.println(Abl.Lambda / 100.0);					
		}
		else
		{
			Serial.print("Cj:");
			Serial.println(Abl.CjState, HEX);
		}
#endif	
		Abl.LastSerialTick = Abl.Tick;
	}
}

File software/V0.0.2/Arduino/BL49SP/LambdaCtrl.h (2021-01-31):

/* LambdaCtrl.h
 *	
 *	This is the main header for the project.
 *	Here are all defines, objects and function prototypes
 *
 *	Mario Schöbinger
 *	2018/11
 *
 **/

#pragma once

#include <Arduino.h>
#include <SPI.h>
#include <stdint.h>
#include <FastPID.h>
#include <Wire.h>
#include <avr/eeprom.h>

/* Define IO */
#define CJ125_NSS_PIN                    	10   	/* Pin used for chip select in SPI communication. */  
#define LED_STATUS_POWER                 	7   	/* Pin used for power the status LED, indicating we have power. */
#define LED_STATUS_HEATER                	5   	/* Pin used for the heater status LED, indicating heater activity. */
#define HEATER_OUTPUT_PIN                	6  	/* Pin used for the PWM output to the heater circuit. */
#define USUP_ANALOG_INPUT_PIN            	A0  	/* Analog input for power supply.*/
#define UVREF_ANALOG_INPUT_PIN           	A1  	/* Analog input for reference voltage supply.*/
#define UR_ANALOG_INPUT_PIN              	A6  	/* Analog input for temperature.*/
#define UA_ANALOG_INPUT_PIN              	A7  	/* Analog input for lambda.*/
#define LAMBDA_PWM_OUTPUT_PIN            	3   	/* spare analog output (narrow band simulation or AFR Gauge 0-1V/0-5V) */
#define EN_INPUT_PIN                     	16  	/* Enable pin, low when engine running */
//#define SP1_INPUT_PIN             	        2   	/* Spare input 1 */
//#define SP2_INPUT_PIN               	 	4   	/* Spare input 2 */

/* Define parameters */
#define START_CONF_CNT				10	// Startup confident count, Min < UBatterie < Max, CJ Status ok
#define CJ_OK_CONF_CNT				10	// Cj read with status ready confident count 

#define CJ_CALIBRATION_SAMPLES			10	// Read values this time and build average (10)
#define CJ_CALIBRATION_PERIOD			150	// Read a value every xx milliseconds  (150)

#define CJ_PUMP_FACTOR				1000	// 1000 according to datasheet
#define CJ_PUMP_RES_SHUNT			61.9	// 61,9 Ohm according to datasheet

#define CJ_ERR_CNT				2	// xx Reads with error triggers a error for cj
#define LAMBDA_PERIOD				17	// Every xx milliseconds calculate lambda		

#define UA_MIN_VALUE				150	// Min allowed calibration value								
#define UA_MAX_VALUE				400	// Max allowerd calibration value

#define UR_MIN_VALUE				150	// Min allowed calibration value
#define UR_MAX_VALUE				300	// Max allowerd calibration value

#define USUP_MIN_ERR				10500	// Min allowed supply voltage value
#define USUP_MAX_ERR				17000	// Max allowed supply voltage value

#define USUP_MIN_OK				11000	// Min allowed supply voltage value
#define USUP_MAX_OK				16500	// Max allowed supply voltage value

#define USUP_ERR_CNT				3	// Allowed error count, switch to preset if supply out of range for this count

#define PROBE_CONDENSATE_PERIOD		    	6000	// xx milliseconds 
#define PROBE_CONDENSATE_VOLT		    	1500	// xx millivolt during condensate heat
#define PROBE_CONDENSATE_LIMIT		    	34	// 34 is the value which is used for 11V supply voltage 

#define PROBE_PREHEAT_PERIOD		    	1000	// xx milliseconds between each step (1000ms)
#define PROBE_PREHEAT_STEP		    	400		// xx millivolt per step (400mV)
#define PROBE_PREHEAT_MAX		    	13000	// xx millivolt for end preheat, after this we go to pid
#define PROBE_PREHEAT_TIMOUT		    	15000	// xx milliseconds preheat timeout (15000ms)

#define PROBE_PID_PERIOD		    	10	// xx milliseconds

#define DEBUG					1	// Define debug mode 0 = off, 1 = Minimum, 2= all

/* Define CJ125 registers */
#define CJ125_IDENT_REG_REQUEST             	0x4800	/* Identify request, gives revision of the chip. */
#define CJ125_DIAG_REG_REQUEST              	0x7800  /* Dignostic request, gives the current status. */
#define CJ125_INIT_REG1_REQUEST             	0x6C00  /* Requests the first init register. */
#define CJ125_INIT_REG2_REQUEST             	0x7E00  /* Requests the second init register. */
#define CJ125_INIT_REG1_MODE_CALIBRATE      	0x569D  /* Sets the first init register in calibration mode. */
#define CJ125_INIT_REG1_MODE_NORMAL_V8      	0x5688  /* Sets the first init register in operation mode. V=8 amplification. */
#define CJ125_INIT_REG1_MODE_NORMAL_V17     	0x5689  /* Sets the first init register in operation mode. V=17 amplification. */
#define CJ125_DIAG_REG_STATUS_OK            	0x28FF  /* The response of the diagnostic register when everything is ok. */
#define CJ125_DIAG_REG_STATUS_NOPOWER       	0x2855  /* The response of the diagnostic register when power is low. */
#define CJ125_DIAG_REG_STATUS_NOSENSOR      	0x287F  /* The response of the diagnostic register when no sensor is connected. */
#define CJ125_INIT_REG1_STATUS_0            	0x2888  /* The response of the init register when V=8 amplification is in use. */
#define CJ125_INIT_REG1_STATUS_1            	0x2889  /* The response of the init register when V=17 amplification is in use. */

/* Define DAC MCP4725 address MCP4725A2T-E/CH */
#define DAC1_ADDR				0x60	/* Address for DAC 1 chip A0 tied to GND */

/* Define DAC MCP4725 registers */
#define MCP4725_CMD_WRITEDAC			0x40	/* Writes data to the DAC */
#define MCP4725_CMD_WRITEDACEEPROM		0x60  	/* Writes data to the DAC and the EEPROM (persisting the assigned value after reset) */

/* Lambda Outputs are defined as follow:
 *	
 *	0.5V = 0,68 Lambda = 10 AFR (Gasoline)
 *	4,5V = 1,36 Lambda = 20 AFR (Gasoline)
 *
 *	Internal Lambda is used in a range from 68..136
 *	
 **/
#define LambdaToVoltage(a) ((a * 5882UL / 100UL) - 3500UL)
#define VoltageTo8BitDac(a) (a * 255UL / 5000UL)			
#define VoltageTo12BitDac(a) (a * 4095UL / 5000UL)

/* Calculate millivolt from adc */
#define AdcToVoltage(a) (a * 5000UL / 1023UL)

typedef enum{
	INVALID = 0,
	PRESET,
	START,
	CALIBRATION,
	IDLE,
	CONDENSATE,
	PREHEAT,
	PID,
	RUNNING,
	ERROR
} state;

typedef enum
{
	cjINVALID,
	cjCALIBRATION,
	cjNORMALV8,
	cjNORMALV17,
	cjERROR,
} cjmode;

typedef struct
{
	uint8_t StartConfCnt;
	uint8_t CjConfCnt;
	uint8_t CjCalSamples;
	uint8_t CjCalPeriod;
	uint8_t CjErrCnt;
	uint8_t LambdaPeriod;
	uint8_t SupplErrCnt;
	uint16_t tCondensate;
	uint16_t tPreheat;
}tCfg;

typedef struct
{
	uint8_t Mode;
	uint16_t Flags;
	uint32_t Tick;
	uint32_t LastHeatTick;
	uint32_t LastCjTick;
	uint32_t StartHeatTick;
	uint32_t LastSerialTick;
	uint32_t LastErrorTick;
	int16_t VoltageOffset;
	int16_t	SupplyVoltage;
	uint8_t SupplyErrCnt;
	int16_t RefVoltage;
	uint16_t CjState;	
	uint8_t CjMode;
	uint8_t CjErrCnt;
	uint16_t UAOpt;
	uint16_t UROpt;
	uint8_t HeatState;
	int16_t Lambda;
} tAbl;

typedef struct
{
	int16_t UA;
	int16_t UR;
	int16_t USup;
	int16_t URef;
	uint8_t EN;
	uint8_t S1;
	uint8_t S2;		
} tInputs;

typedef struct
{
	uint8_t Heater;
	uint8_t Wbl;
	uint16_t Dac1;
	uint16_t Dac2;
	uint8_t Led1;
	uint8_t Led2;
} tOutputs;

typedef struct
{
	int16_t IP;
	int16_t UR;
	int16_t UB;
	
} tCj125;


const static char ModeName[][15] =
{
	{ "INVALID" },
	{ "PRESET" },
	{ "START" },
	{ "CALIBRATION" },
	{ "IDLE" },
	{ "CONDENSATION" },
	{ "PREHEAT" },
	{ "PID" },
	{ "RUNNING" },
	{ "ERROR" },		
};

extern FastPID HeaterPid;
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

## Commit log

2020-04-17 Update BL49SP.ino
    Factor for SupplyVoltage corrected
    [BL49SP.ino]
2020-05-11 Update BL49SP.ino
    Enabled internal pullup resistor on enable pin
2020-09-04 Update BL49SP.ino
    fixed typo Serial.println(Cj.Ip) --> Serial.println(Cj.IP)
    [BL49SP.ino]
2022-11-08 :up: Fixed bug in debug output
    Debug serial output checks if cjState is okay, but if cj has no erros cjState has infomation of cj running mode...
    So changed to cjState != cjERROR
    [BL49SP.ino, main.cpp]
2022-11-08 fixed possible overflow bug during preheat
    [Helper.ino, helper.cpp]

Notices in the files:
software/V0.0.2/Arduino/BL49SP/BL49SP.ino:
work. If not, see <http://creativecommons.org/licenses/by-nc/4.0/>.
